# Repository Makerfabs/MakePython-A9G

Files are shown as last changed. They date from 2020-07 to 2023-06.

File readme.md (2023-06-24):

# MakePython A9G

```c++
/*
Version:		V1.1
Author:			Vincent
Create Date:	2020/7/24
Note:
	20223/1/31		V1.1: Add Arduino example for AT Command test.
*/
```

[toc]

# Introduce

MakePython A9G is an IOT for GPRS / GSM + GPS module, users can use MicroPython to program it, which is very easy, especially for non-programmers. There is also a user guide to learn how to use the board to create the first IOT project, which allows beginners to quickly learn hardware and programming skills.

With this board, you will easy to add text, SMS and data to your project. It is good for your smart home project or GPS tracker and so on.

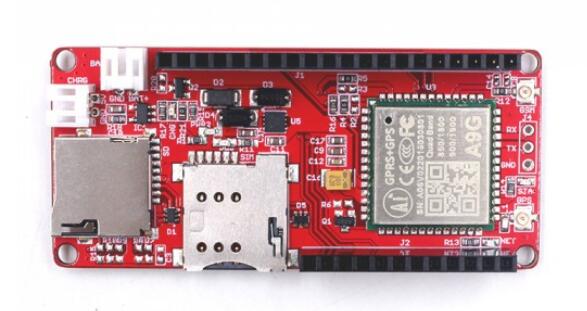
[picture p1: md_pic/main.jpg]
main


- You can get one from: [MakePython A9G](https://www.makerfabs.com/makepython-a9g-gprs-gps-shield.html)

- Hardware and detailed instructions please visit Wiki page: [MakePython A9G Wiki](https://wiki.makerfabs.com/MaESP_A9G.html)

# Related Test

Visit the wiki for details.

- Shows the GPS location on OLED display

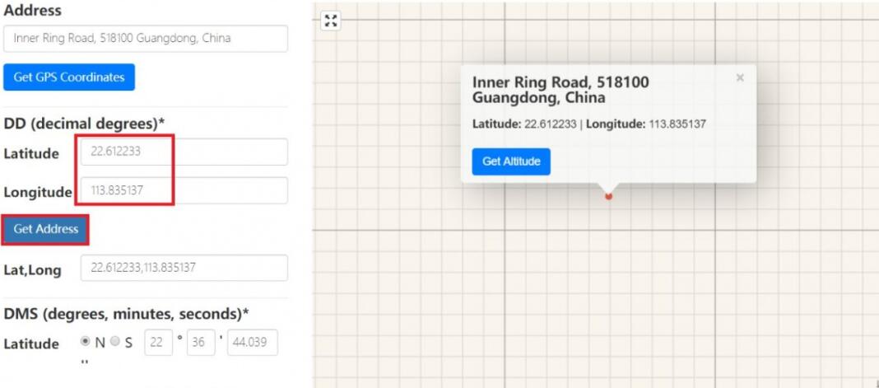
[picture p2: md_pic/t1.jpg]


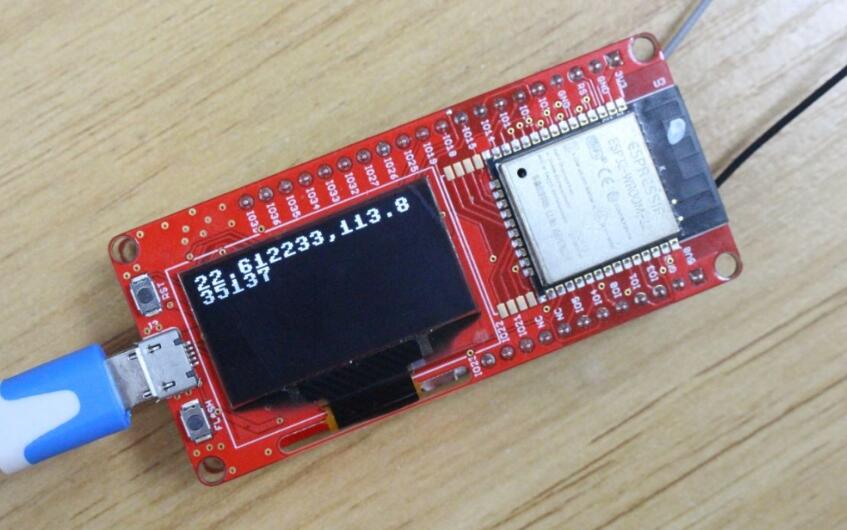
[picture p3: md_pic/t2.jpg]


- Display SMS message on OLED display

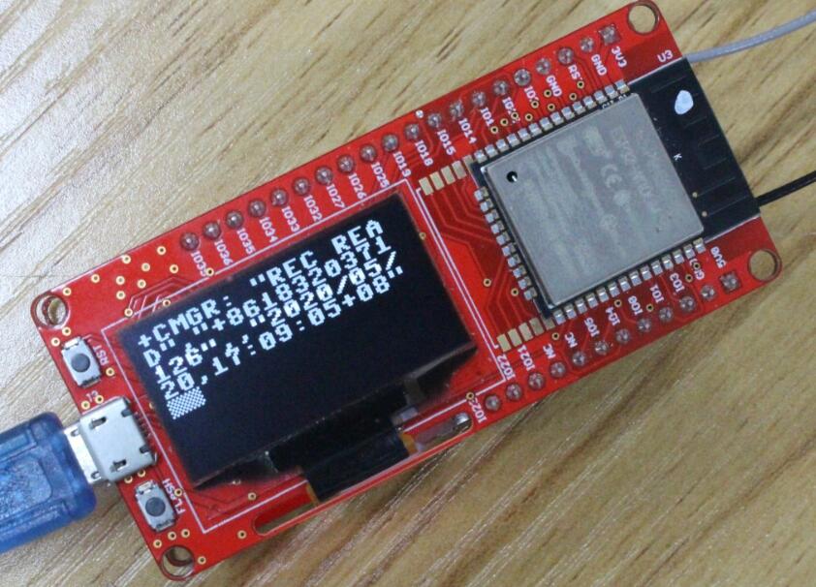
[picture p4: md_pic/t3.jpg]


# Arduino Example

## at_command.ino

The AT instruction of serial port monitor can be forwarded to the A9G module.

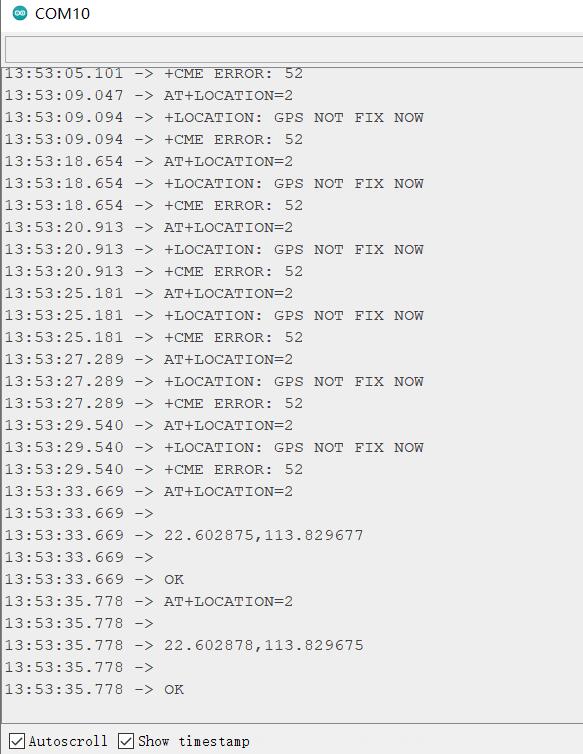
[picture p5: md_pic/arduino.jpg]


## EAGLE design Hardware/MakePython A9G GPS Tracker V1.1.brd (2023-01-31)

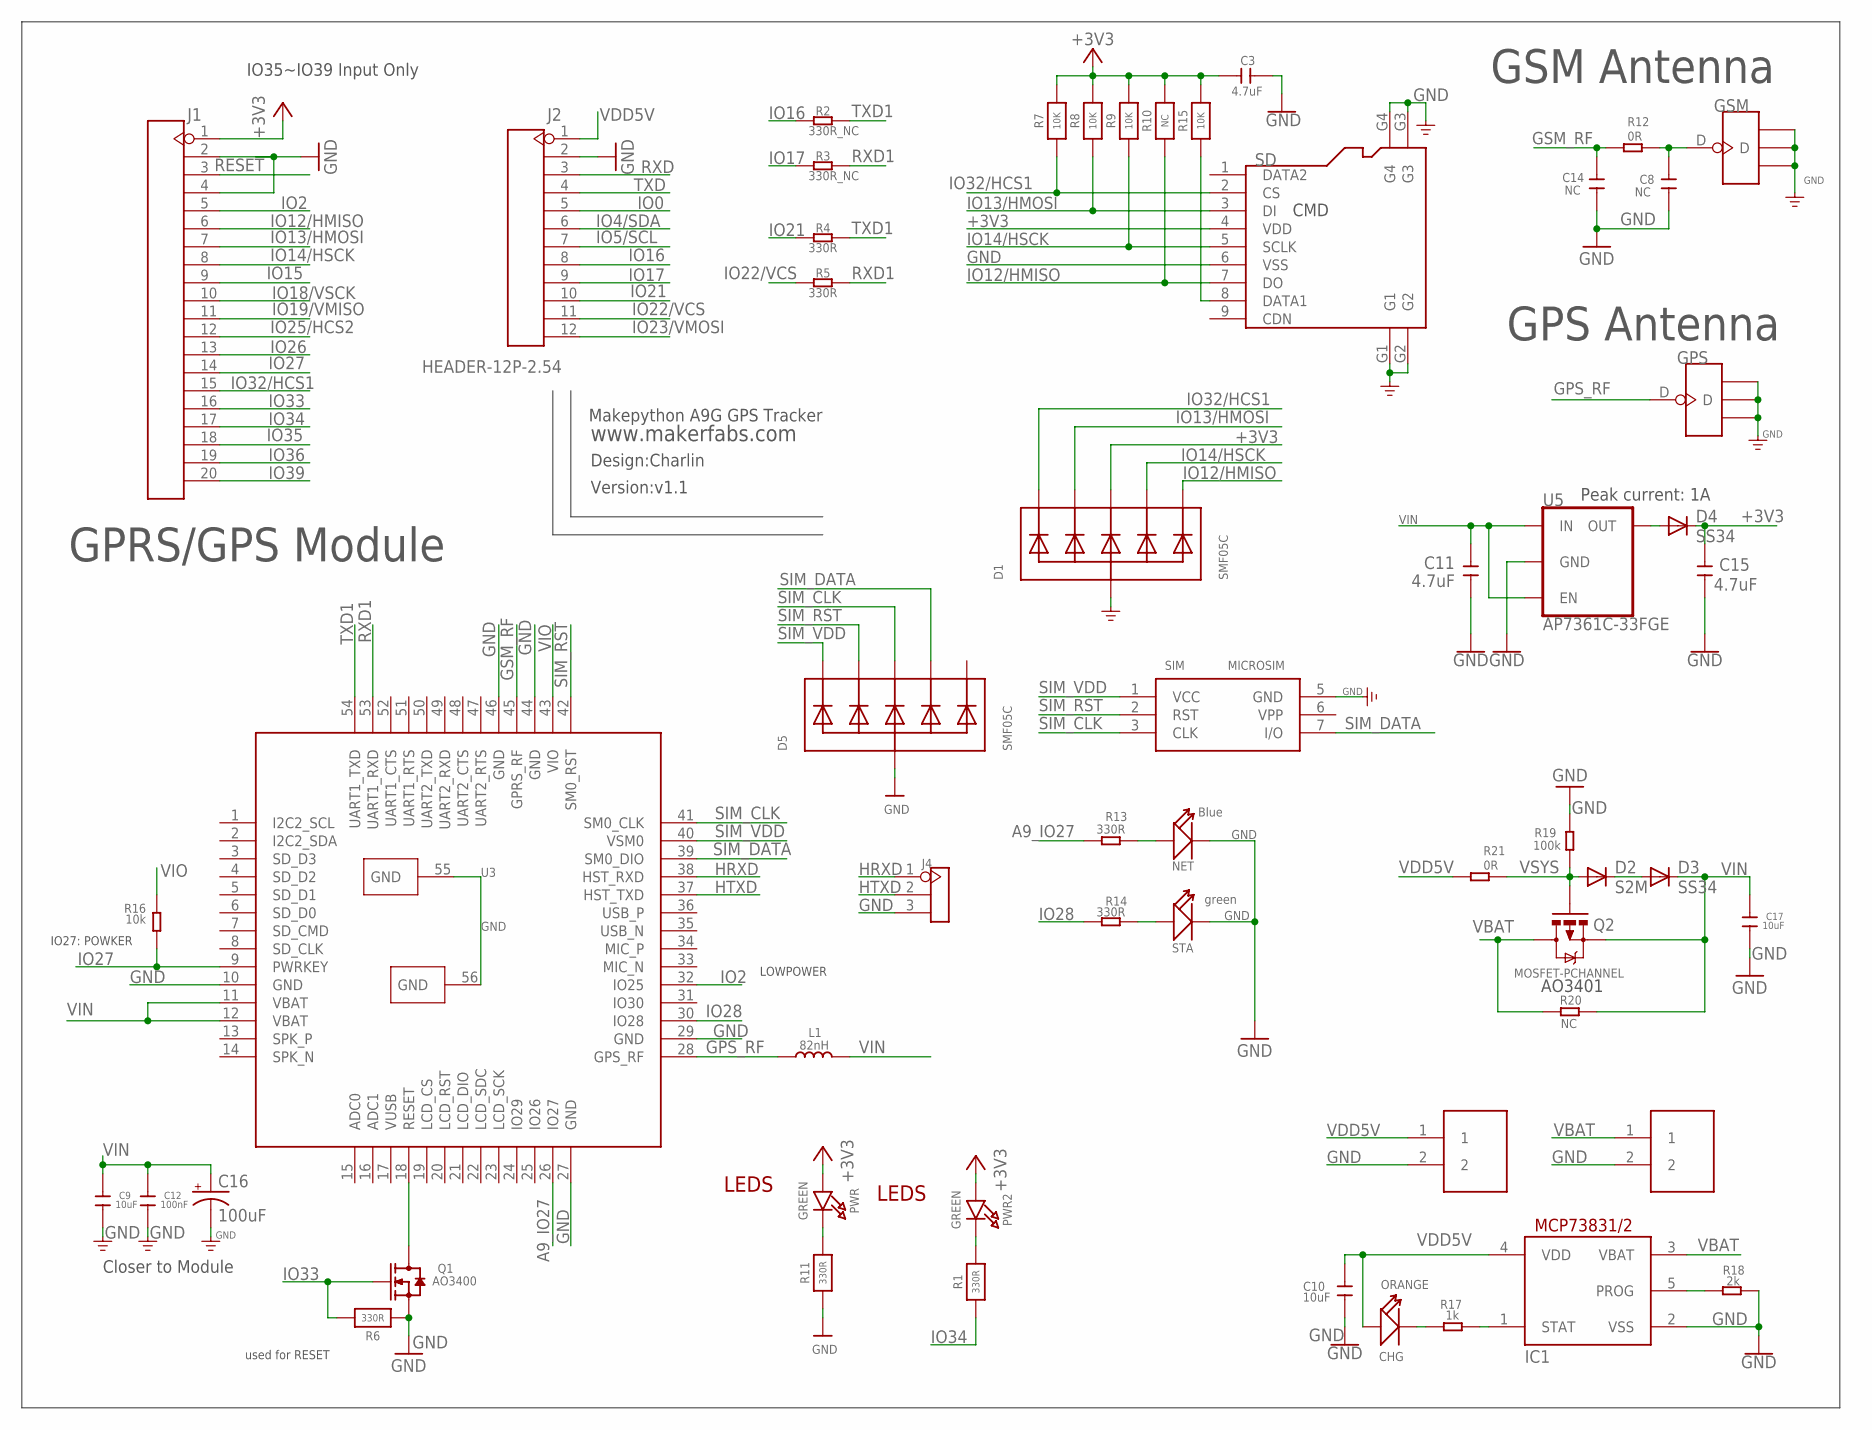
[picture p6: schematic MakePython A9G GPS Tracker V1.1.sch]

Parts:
BAT: PH2.0-2P-90-DIP
C3: 4.7uF; DISCRETE_C0603
C8, C14: NC; C0402
C9, C10, C17: 10uF; C0603
C11, C15: 4.7uF; C0603
C12: 100nF; C0603
C16: 100uF; EIA3528
CHG: ORANGE; D0603
CHRG: PH2.0-2P-90-DIP
D1, D5: SMF05C; SOT363
D2: S2M; DO-214AC
D3, D4: SS34; DO-214AC
GPS: ANTENNA-U-FL; 4P-U-FL
GSM: ANTENNA-U-FL; 4P-U-FL
IC1: MCP73831/OT; SOT23-5L
J1: HEADER-20P-2.54; 20P-2.54
J2: HEADER-12P-2.54; 12P-2.54
J4: HEADER-3P-2.54; 3P-2.54
L1: 82nH; L0603
NET: Blue; LED-0603
PWR, PWR2: GREEN; CHIPLED_0805_NOOUTLINE
Q1: AO3400; SOT23@1
Q2: MOSFET-PCHANNEL; SOT23-3
R1, R6, R11: 330R; 0603-NO
R2, R3: 330R_NC; R0603
R4, R5, R13, R14: 330R; R0603
R7, R8, R9, R15: 10K; 0603-NO
R10: NC; 0603-NO
R12, R21: 0R; R0603
R16: 10k; R0603
R17: 1k; R0603
R18: 2k; R0603
R19: 100k; R0603
R20: NC; R0603
SD: HOLDER-MICROSD-9P; 9P-SMD-W/-RING
SIM: MICROSIM
STA: green; LED-0603
U3: A9G
U5: AP7361C-33FGE; 8-UDFN

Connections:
+3V3: C3.2, C15.2, D1.4 (C3), D4.C, J1.1, PWR.A, PWR2.A, R7.2, R8.2, R9.2, R10.2, R15.2, SD.4 (VDD)
A9_IO27: R13.1, U3.26 (IO27)
GND: BAT.2, C3.1, C8.1, C9.1, C10.1, C11.1, C12.1, C14.1, C15.1, C16.C (-), C17.1, CHRG.2, D1.2 (A), D5.2 (A), GPS.GND1, GPS.GND2, GPS.GND3, GSM.GND1, GSM.GND2, GSM.GND3, IC1.2 (VSS), J1.2, J1.4, J2.2, J4.3, NET.-, Q1.2 (S), R6.1, R11.1, R18.2, R19.2, SD.6 (VSS), SD.G1, SD.G2, SD.G3, SD.G4, SIM.5 (GND), STA.-, U3.10 (GND), U3.27 (GND), U3.29 (GND), U3.44 (GND), U3.46 (GND), U3.55 (GND), U3.56 (GND), U5.4 (GND), U5.EP (GND)
GPS_RF: GPS.D, L1.1, U3.28 (GPS_RF)
GSM_RF: C14.2, R12.1, U3.45 (GPRS_RF)
HRXD: J4.1, U3.38 (HST_RXD)
HTXD: J4.2, U3.37 (HST_TXD)
IO0: J2.5
IO2: J1.5, U3.32 (IO25)
IO4/SDA: J2.6, R15.1, SD.8 (DATA1)
IO5/SCL: J2.7
IO12/HMISO: D1.6 (C5), J1.6, R10.1, SD.7 (DO)
IO13/HMOSI: D1.3 (C2), J1.7, R8.1, SD.3 (DI)
IO14/HSCK: D1.5 (C4), J1.8, R9.1, SD.5 (SCLK)
IO15: J1.9
IO16: J2.8, R2.1
IO17: J2.9, R3.1
IO18/VSCK: J1.10
IO19/VMISO: J1.11
IO21: J2.10, R4.1
IO22/VCS: J2.11, R5.1
IO23/VMOSI: J2.12
IO25/HCS2: J1.12
IO26: J1.13
IO27: J1.14, R16.1, U3.9 (PWRKEY)
IO28: R14.1, U3.30 (IO28)
IO32/HCS1: D1.1 (C1), J1.15, R7.1, SD.2 (CS)
IO33: J1.16, Q1.1 (G), R6.2
IO34: J1.17, R1.1
IO35: J1.18
IO36: J1.19
IO39: J1.20
unnamed: PWR2.C, R1.2
unnamed: D4.A, U5.1 (OUT)
unnamed: R14.2, STA.+
unnamed: PWR.C, R11.2
unnamed: D2.C, D3.A
unnamed: NET.+, R13.2
unnamed: Q1.3 (D), U3.18 (RESET)
unnamed: CHG.-, R17.1
unnamed: IC1.1 (STAT), R17.2
unnamed: IC1.5 (PROG), R18.1
unnamed: C8.2, GSM.D, R12.2
RESET: J1.3
RXD: J2.3
RXD1: R3.2, R5.2, U3.53 (UART1_RXD)
SIM_CLK: D5.4 (C3), SIM.3 (CLK), U3.41 (SM0_CLK)
SIM_DATA: D5.5 (C4), SIM.7 (I/O), U3.39 (SM0_DIO)
SIM_RST: D5.3 (C2), SIM.2 (RST), U3.42 (SM0_RST)
SIM_VDD: D5.1 (C1), SIM.1 (VCC), U3.40 (VSM0)
TXD: J2.4
TXD1: R2.2, R4.2, U3.54 (UART1_TXD)
VBAT: BAT.1, IC1.3 (VBAT), Q2.3 (D), R20.1
VDD5V: C10.2, CHG.+, CHRG.1, IC1.4 (VDD), J2.1, R21.1
VIN: C9.2, C11.2, C12.2, C16.A (+), C17.2, D3.C, L1.2, Q2.2 (S), R20.2, U3.11 (VBAT), U3.12 (VBAT), U5.5 (EN), U5.8 (IN)
VIO: R16.2, U3.43 (VIO)
VSYS: D2.A, Q2.1 (G), R19.1, R21.2

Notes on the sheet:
IO35~IO39 Input Only
Makepython A9G GPS Tracker
LEDS
GSM Antenna
GPS Antenna
GPRS/GPS Module
LOWPOWER
used for RESET
IO27: POWKER
www.makerfabs.com
Design:Charlin
Closer to Module
Version:v1.1
AO3401
Peak current: 1A
CMD

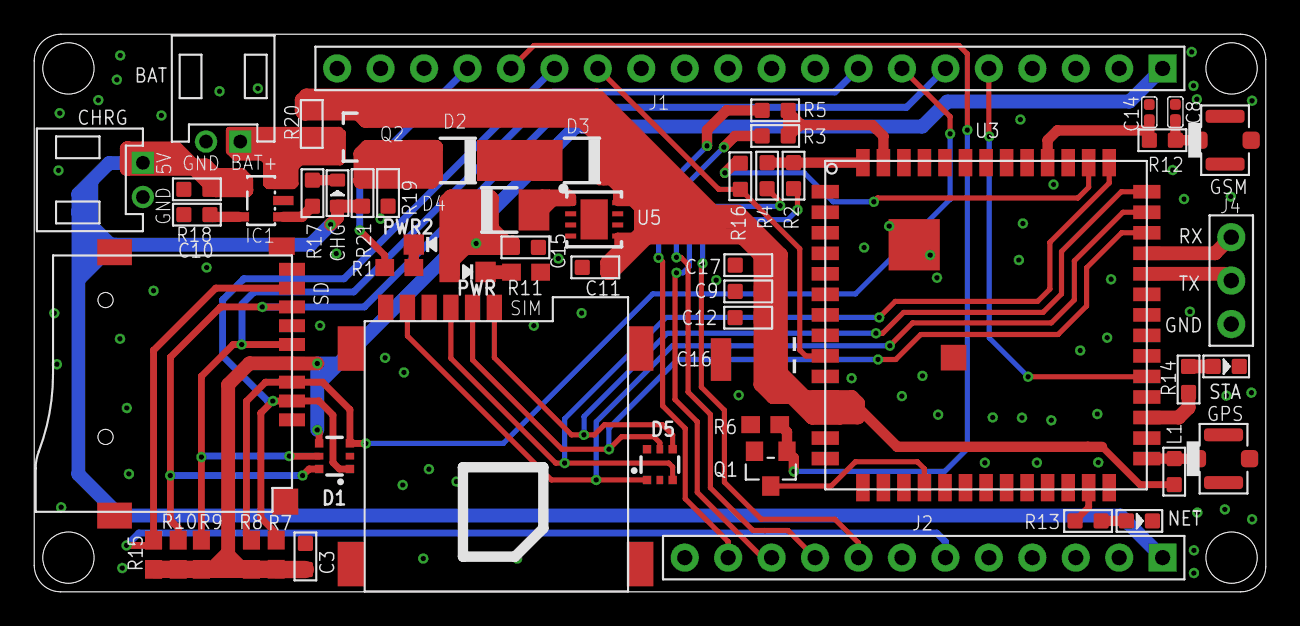
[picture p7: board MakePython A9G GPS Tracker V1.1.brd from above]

Board: 2 copper layers, 72.0 x 32.6 mm, 57 parts (1 on the bottom side), 43 nets.

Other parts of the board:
U$1: MAKERFABS_0.3

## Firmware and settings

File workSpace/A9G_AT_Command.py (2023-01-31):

from machine import UART,Pin,I2C
import machine

import utime

uart = UART(2, baudrate=115200, rx=21, tx=22,timeout=10)
uart1 = UART(1, baudrate=115200, rx=3, tx=1,timeout=10)

A9G_RESET_PIN = Pin(33, Pin.OUT) 
A9G_RESET_PIN.value(0)             

utime.sleep_ms(2000)
A9G_PWR_KEY = Pin(27, Pin.OUT) 
A9G_PWR_KEY.value(0)
utime.sleep_ms(2000)
A9G_PWR_KEY.value(1)
utime.sleep_ms(20000)


if True:
    
    uart1.write('AT\r\n')#1: turn on GPS  0:Turn off GPS
    uart1.write('Hello world!')#1: turn on GPS  0:Turn off GPS
    utime.sleep_ms(1000)
    while True:      
         if uart.any():
            
            bin_data = uart.readline()
            uart1.write(bin_data)         
         if uart1.any():
            
            bin_data = uart1.readline()
            uart.write(bin_data)         

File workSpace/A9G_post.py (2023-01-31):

from machine import UART,Pin,I2C
import machine

import utime

uart = UART(2, baudrate=115200, rx=21, tx=22,timeout=10)

A9G_RESET_PIN = Pin(33, Pin.OUT) 
A9G_RESET_PIN.value(0)             

utime.sleep_ms(2000)
A9G_PWR_KEY = Pin(27, Pin.OUT) 
A9G_PWR_KEY.value(0)
utime.sleep_ms(2000)
A9G_PWR_KEY.value(1)
utime.sleep_ms(20000)


if True:
    
    uart.write('AT\r\n')#1: turn on GPS  0:Turn off GPS
    utime.sleep_ms(1000)
    uart.write('AT+CCID\r\n')
    utime.sleep_ms(1000)
    uart.write('AT+CREG?\r\n')
    utime.sleep_ms(1000)
    uart.write('AT+CGATT=1\r\n')
    utime.sleep_ms(1000)
    
    uart.write('AT+CGDCONT=1,\"IP\",\"CMNET\"\r\n')
    utime.sleep_ms(1000)
    uart.write('AT+CGACT=1,1\r\n')
    utime.sleep_ms(1000)
    uart.write('AT+HTTPPOST=\"http://music.163.com/\",\"text/plain\",\"helloworld\"\r\n')
    utime.sleep_ms(1000)
    utime.sleep_ms(1000)
    while True:      
         if uart.any():
            
            bin_data = uart.readline()
            print(bin_data)
            
            utime.sleep_ms(1000)

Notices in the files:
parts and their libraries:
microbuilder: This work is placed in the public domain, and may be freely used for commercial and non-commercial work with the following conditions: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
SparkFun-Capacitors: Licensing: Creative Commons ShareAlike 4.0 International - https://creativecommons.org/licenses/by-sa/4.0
